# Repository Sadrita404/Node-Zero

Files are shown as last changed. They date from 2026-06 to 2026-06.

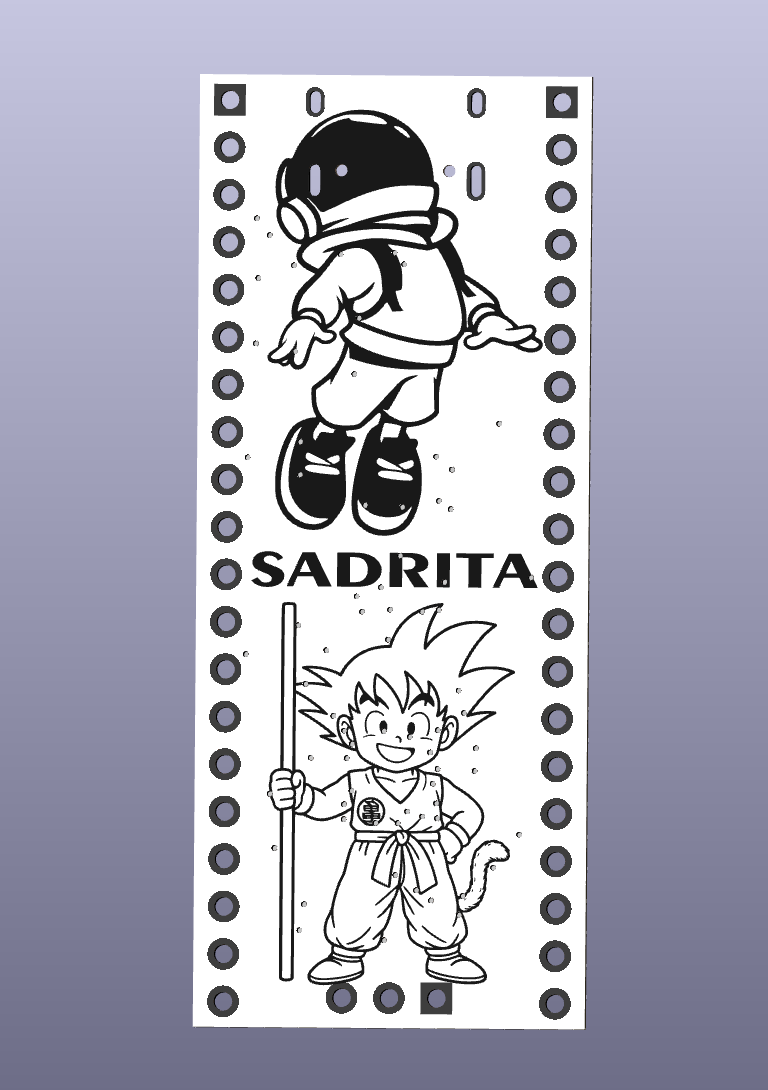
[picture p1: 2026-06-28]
Images/22.png

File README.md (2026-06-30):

<div align="center">
  <table border="0" cellpadding="0" cellspacing="0">
    <tr>
      <td align="center" style="background: #ffffff; border: 1px solid #d0d7de; border-radius: 12px; padding: 16px; box-shadow: 0 4px 12px rgba(0,0,0,0.05);">
        Rough Layout For The PCB
        <div style="margin-top: 12px; font-family: -apple-system, BlinkMacSystemFont, 'Segoe UI', Helvetica, Arial, sans-serif; font-size: 13px; color: #57606a; font-weight: 500;">
      </td>
    </tr>
  </table>
</div>

| Title | Node Zero |
| :-- | :---|
|Author |Sadrita Neogi|

## What's this?

Node Zero is an  rp2040 based micro-controller unit that consist of the rp2040 micro processor, the 16Mbit SPI NOR Flash, a crystal oscillator that synchronizes communication in the board between the USB abd rp2040, a voltage regulator, reset and boot switch.

## Why I built it ?

This is the starter project of stasis and I have not make any dev board ever before, so this is my the first time I am making an dev board so I am very excited to build this. That's why I am making the PCB whole custom thing. I have also get help from the detailed guide that is provided on the stasis website.

<div align="center">

| | PCB Designing | |
| :---: | :---: | :---: |
| Design 1 | Design 2 | Design 3 |
| Design 4 | Design 5 | Design 6 |
| Design 7 | Design 8 | Design 9 |

Screenshot 2026-06-30 at 8 58 29 PM

<div align="center">
  <h2> Final Look </h2>
  <table border="0" cellpadding="10" cellspacing="0" style="border-collapse: collapse;">
    <tr>
      <!-- FRONT SIDE CARD -->
      <td align="center" valign="top" width="50%" style="background: #ffffff; border: 1px solid #d0d7de; border-radius: 12px; padding: 16px; box-shadow: 0 4px 12px rgba(0,0,0,0.05);">
        Front Side View
        <div style="margin-top: 12px; font-family: -apple-system, BlinkMacSystemFont, 'Segoe UI', Helvetica, Arial, sans-serif; font-size: 13px; color: #57606a; font-weight: 600; text-transform: uppercase; letter-spacing: 0.5px;">
          ▲ Front Side View
        </div>
      </td>
      <!-- SPACER FOR GITHUB MOBILE DEGRADATION -->
      <td width="2%">&nbsp;</td>
      <!-- BACK SIDE CARD -->
      <td align="center" valign="top" width="50%" style="background: #ffffff; border: 1px solid #d0d7de; border-radius: 12px; padding: 16px; box-shadow: 0 4px 12px rgba(0,0,0,0.05);">
        Back Side View
        <div style="margin-top: 12px; font-family: -apple-system, BlinkMacSystemFont, 'Segoe UI', Helvetica, Arial, sans-serif; font-size: 13px; color: #57606a; font-weight: 600; text-transform: uppercase; letter-spacing: 0.5px;">
          ▲ Back Side View
        </div>
      </td>
    </tr>
  </table>
</div>
</div>

<div align="center">
  <h2> Bill of Materials </h2>
</div>

| Name | Purpose | Qty | Total (USD) | Link | Distributor |
| :--- | :--- | :---: | :---: | :---: | :--- |
| C9,C12 | 1uF 10V X5R ±10% 0402 MLCC | 20 | 0.1220 | [Link](https://lcsc.com/product-detail/C14445.html) | JLCPCB |
| C10,C11,C5,C8,C3,C2,C7,C6,C4,C17,C1,C20,C18 | 0.1uF (100nF) 16V X7R ±10% 0402 MLCC | 75 | 0.5775 | [Link](https://lcsc.com/product-detail/C1525.html) | JLCPCB |
| C13,C14 | 10uF 25V X5R ±10% 0805 MLCC | 20 | 4.3840 | [Link](https://lcsc.com/product-detail/C15850.html) | JLCPCB |
| C16,C15 | 33pF 50V C0G ±5% 0402 MLCC | 20 | 0.1160 | [Link](https://lcsc.com/product-detail/C1562.html) | JLCPCB |
| C19 | 10nF 50V X7R ±10% 0402 MLCC | 20 | 0.1740 | [Link](https://lcsc.com/product-detail/C15195.html) | JLCPCB |
| C21 | 2.2uF 6.3V X5R ±20% 0402 MLCC | 20 | 0.1660 | [Link](https://lcsc.com/product-detail/C12530.html) | JLCPCB |
| D3,D1,D2 | Red Water Clear 0603 LED Indication | 25 | 0.1800 | [Link](https://lcsc.com/product-detail/C2286.html) | JLCPCB |
| J1 | USB Type-C Receptacle 16P Female SMD R/A | 5 | 0.9170 | [Link](https://lcsc.com/product-detail/C165948.html) | JLCPCB |
| R2,R1 | 5.1kΩ 50V 62.5mW Thick Film Resistor ±1% 0402 | 20 | 0.0200 | [Link](https://lcsc.com/product-detail/C25905.html) | JLCPCB |
| R4,R3 | 30Ω 50V 62.5mW Thick Film Resistor ±5% 0402 | 20 | 0.0240 | [Link](https://lcsc.com/product-detail/C137883.html) | JLCPCB |
| R5,R7 | 1kΩ 50V 62.5mW Thick Film Resistor ±1% 0402 | 20 | 0.0820 | [Link](https://lcsc.com/product-detail/C11702.html) | JLCPCB |
| R6 | 10kΩ 50V 62.5mW Thick Film Resistor ±1% 0402 | 20 | 0.0640 | [Link](https://lcsc.com/product-detail/C25744.html) | JLCPCB |
| R10,R9,R8 | 470Ω 50V 62.5mW Thick Film Resistor ±1% 0402 | 25 | 0.0300 | [Link](https://lcsc.com/product-detail/C25117.html) | JLCPCB |
| SW1 | Tactile Switches 12V 50mA Black Button SMD SPST | 9 | 0.4950 | [Link](https://lcsc.com/product-detail/C720477.html) | JLCPCB |
| U1 | RP2040 Microcontroller (MCU) 133MHz LQFN-56 | 5 | 4.9045 | [Link](https://lcsc.com/product-detail/C2040.html) | JLCPCB |
| U2 | MCP1700T-3302E/TT Fixed 3.3V 250mA Linear LDO | 5 | 2.1595 | [Link](https://lcsc.com/product-detail/C39051.html) | JLCPCB |
| U3 | W25Q16JVUXIQ 16Mbit 133MHz SPI NOR FLASH USON-8 | 5 | 7.8745 | [Link](https://lcsc.com/product-detail/C2843335.html) | JLCPCB |
| U4 | ICM-20608-G 6-Axis IMU Accel + Gyro LGA-16 | 2 | 26.3282 | [Link](https://lcsc.com/product-detail/C78569.html) | JLCPCB |
| Y1 | 12MHz 20pF Crystal Oscillator SMD3225-4P | 7 | 0.6972 | [Link](https://lcsc.com/product-detail/C9002.html) | JLCPCB |
| PCB Fabrication (Node_Zero)	| 2-layer PCB — the board itself| 	5	| $2.00 |	—	 | JLCPCB |
| PCBA SMT Assembly|	SMT assembly of all SMD components| 	2| 	$41.63	| —	| JLCPCB |
| Shipping PCB	| E- Post (Cheapest) | 	- |	$11.74	| — | 	JLCPCB |
| Total | | | $104.69 | | | |

The project budget is $100 and my BOM is a $4 over that right now. But since I already have another project approved (a PCB business card),and I  order them both together that will cut down on shipping costs and bring the total under $100.

Also, this is my first time building a dev board and I don't have any experience soldering SMD components. Since I don't own a hot plate,So I wouldn't be able to assemble it manually myself and finish the project. So, to stay within that $100 budget, I'm going with PCB assembly instead.

#### Please approve this project it's my first devboard ....

**Project Under Hack Club**

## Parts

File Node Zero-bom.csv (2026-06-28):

Name | Purpose | Quantity | Total Cost (USD) | Link | Distributor
PCBA SMT Assembly | SMT assembly of all SMD components | 2 | 41.63 |  | JLCPCB
C10,C11,C5,C8,C3,C2,C7,C6,C4,C17,C1,C20,C18 | 0.1uF (100nF) 16V X7R ±10% 0402 MLCC | 75 | 0.58 | https://lcsc.com/product-detail/C1525.html | JLCPCB
C13,C14 | 10uF 25V X5R ±10% 0805 MLCC | 20 | 4.38 | https://lcsc.com/product-detail/C15850.html | JLCPCB
C16,C15 | 33pF 50V C0G ±5% 0402 MLCC | 20 | 0.12 | https://lcsc.com/product-detail/C1562.html | JLCPCB
C19 | 10nF 50V X7R ±10% 0402 MLCC | 20 | 0.17 | https://lcsc.com/product-detail/C15195.html | JLCPCB
C21 | 2.2uF 6.3V X5R ±20% 0402 MLCC | 20 | 0.17 | https://lcsc.com/product-detail/C12530.html | JLCPCB
D3,D1,D2 | Red Water Clear 0603 LED Indication | 25 | 0.18 | https://lcsc.com/product-detail/C2286.html | JLCPCB
J1 | USB Type-C Receptacle 16P Female SMD R/A | 5 | 0.92 | https://lcsc.com/product-detail/C165948.html | JLCPCB
R2,R1 | 5.1kΩ 50V 62.5mW Thick Film Resistor ±1% 0402 | 20 | 0.02 | https://lcsc.com/product-detail/C25905.html | JLCPCB
R4,R3 | 30Ω 50V 62.5mW Thick Film Resistor ±5% 0402 | 20 | 0.02 | https://lcsc.com/product-detail/C137883.html | JLCPCB
C9,C12 | 1uF 10V X5R ±10% 0402 MLCC | 20 | 0.12 | https://lcsc.com/product-detail/C14445.html | JLCPCB
R6 | 10kΩ 50V 62.5mW Thick Film Resistor ±1% 0402 | 20 | 0.06 | https://lcsc.com/product-detail/C25744.html | JLCPCB
R10,R9,R8 | 470Ω 50V 62.5mW Thick Film Resistor ±1% 0402 | 25 | 0.03 | https://lcsc.com/product-detail/C25117.html | JLCPCB
SW1 | Tactile Switches 12V 50mA Black Button SMD SPST | 9 | 0.49 | https://lcsc.com/product-detail/C720477.html | JLCPCB
U1 | RP2040 Microcontroller (MCU) 133MHz LQFN-56 | 5 | 4.90 | https://lcsc.com/product-detail/C2040.html | JLCPCB
U2 | MCP1700T-3302E/TT Fixed 3.3V 250mA Linear LDO | 5 | 2.16 | https://lcsc.com/product-detail/C39051.html | JLCPCB
U3 | W25Q16JVUXIQ 16Mbit 133MHz SPI NOR FLASH USON-8 | 5 | 7.87 | https://lcsc.com/product-detail/C2843335.html | JLCPCB
U4 | ICM-20608-G 6-Axis IMU Accel + Gyro LGA-16 | 2 | 26.33 | https://lcsc.com/product-detail/C78569.html | JLCPCB
Y1 | 12MHz 20pF Crystal Oscillator SMD3225-4P | 7 | 0.70 | https://lcsc.com/product-detail/C9002.html | JLCPCB
PCB Fabrication (Node_Zero) | 2-layer PCB — the board itself | 5 | 2.00 |  | JLCPCB
R5,R7 | 1kΩ 50V 62.5mW Thick Film Resistor ±1% 0402 | 20 | 0.08 | https://lcsc.com/product-detail/C11702.html | JLCPCB

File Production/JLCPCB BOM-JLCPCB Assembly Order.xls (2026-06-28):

JLCPCB BOM Tool - BOM Matching
BOM name：JLCPCB BOM-JLCPCB Assembly Order.xlsx |  |  | Download Time：2026-06-28 22:19:41 |  |  |  | * Our matching results are updated in real-time, but stock and prices may change. If it's been over 24 hours, please re-match before placing your order.
PCB Assembled Qty：5 |  |  | Est. Total Price：53.8907
Your BOM |  |  |  |  | Matched Parts |  |  |  |  |  |  | Order Information
Top Designator | Bottom Designator | Comment | Footprint | JLCPCB Part # | Matches | Part # | Manufacturer | Footprint | Description | Category | Warning | JLCPCB Part # | Product link | Lib Type | Qty | Source | Total Price ($)
C9,C12 |  | 1uF | C_0402_1005Metric |  | Select by System | CL05A105KP5NNNC | Samsung Electro-Mechanics | 0402 | 10V 1uF X5R ±10% 0402 Multilayer Ceramic Capacitors MLCC - SMD/SMT ROHS | Multilayer Ceramic Capacitors MLCC - SMD/SMT |  | C14445 | https://jlcpcb.com/partdetail/15107-CL05A105KP5NNNC/C14445 | Extended | 20 | 20 JLCPCB | 0.122
C10,C11,C5,C8,C3,C2,C7,C6,C4,C17,C1,C20,C18 |  | 0.1uF | C_0402_1005Metric |  | Select by System | CL05B104KO5NNNC | Samsung Electro-Mechanics | 0402 | 100nF 16V X7R ±10% 0402 Multilayer Ceramic Capacitors MLCC - SMD/SMT ROHS | Multilayer Ceramic Capacitors MLCC - SMD/SMT |  | C1525 | https://jlcpcb.com/partdetail/1877-CL05B104KO5NNNC/C1525 | Basic | 75 | 75 JLCPCB | 0.5775
C13,C14 |  | 10uF | C_0201_0603Metric |  | Select by System | CL21A106KAYNNNE | Samsung Electro-Mechanics | 0805 | 10uF 25V X5R ±10% 0805 Multilayer Ceramic Capacitors MLCC - SMD/SMT ROHS | Multilayer Ceramic Capacitors MLCC - SMD/SMT |  | C15850 | https://jlcpcb.com/partdetail/16532-CL21A106KAYNNNE/C15850 | Basic | 20 | 20 JLCPCB | 4.384
C16,C15 |  | 33pF | C_0402_1005Metric |  | Select by System | 0402CG330J500NT | FH (Guangdong Fenghua Advanced Tech) | 0402 | 33pF 50V C0G ±5% 0402 Multilayer Ceramic Capacitors MLCC - SMD/SMT ROHS | Multilayer Ceramic Capacitors MLCC - SMD/SMT |  | C1562 | https://jlcpcb.com/partdetail/1914-0402CG330J500NT/C1562 | Basic | 20 | 20 JLCPCB | 0.116
C19 |  | 10nF | C_0402_1005Metric |  | Select by System | CL05B103KB5NNNC | Samsung Electro-Mechanics | 0402 | 10nF 50V X7R ±10% 0402 Multilayer Ceramic Capacitors MLCC - SMD/SMT ROHS | Multilayer Ceramic Capacitors MLCC - SMD/SMT |  | C15195 | https://jlcpcb.com/partdetail/15869-CL05B103KB5NNNC/C15195 | Basic | 20 | 20 JLCPCB | 0.174
C21 |  | 2.2uF | C_0402_1005Metric |  | Select by System | CL05A225MQ5NSNC | Samsung Electro-Mechanics | 0402 | 2.2uF 6.3V X5R ±20% 0402 Multilayer Ceramic Capacitors MLCC - SMD/SMT ROHS | Multilayer Ceramic Capacitors MLCC - SMD/SMT |  | C12530 | https://jlcpcb.com/partdetail/13164-CL05A225MQ5NSNC/C12530 | Basic | 20 | 20 JLCPCB | 0.166
D3,D1,D2 |  | LED | LED_0603_1608Metric |  | Select by System | KT-0603R | Hubei KENTO Elec | 0603 | -40℃~+85℃ 1.8V~2.4V 120° 20mA 300mcd 40mW 615nm~630nm 645nm Discrete Diode Red Water Clear 0603 LED Indication - Discrete ROHS | LED Indication - Discrete |  | C2286 | https://jlcpcb.com/partdetail/Hubei_KENTOElec-KT0603R/C2286 | Basic | 25 | 25 JLCPCB | 0.18
J1 |  | USB_C_Receptacle_USB2.0_14P | USB_C_Receptacle_HRO_TYPE-C-31-M-12 |  | Select by System | TYPE-C-31-M-12 | Korean Hroparts Elec | SMD | -30℃~+80℃ 1 10,000 cycles 16P 20V 5A 7.35mm Female Surface Mount, Right Angle Type-C SMD USB Connectors ROHS | USB Connectors |  | C165948 | https://jlcpcb.com/partdetail/Korean_HropartsElec-TYPE_C_31_M12/C165948 | Extended | 5 | 5 JLCPCB | 0.917
R2,R1 |  | 5.1K | R_0402_1005Metric |  | Select by System | 0402WGF5101TCE | UNI-ROYAL(Uniroyal Elec) | 0402 | -55℃~+155℃ 5.1kΩ 50V 62.5mW Thick Film Resistor ±1% ±100ppm/℃ 0402 Chip Resistor - Surface Mount ROHS | Chip Resistor - Surface Mount |  | C25905 | https://jlcpcb.com/partdetail/26648-0402WGF5101TCE/C25905 | Basic | 20 | 20 JLCPCB | 0.02
R4,R3 |  | 27 | R_0402_1005Metric |  | Select by Customer | RC0402JR-07300RL | YAGEO | 0402 | -55℃~+155℃ 300Ω 50V 62.5mW Thick Film Resistor ±100ppm/℃ ±5% 0402 Chip Resistor - Surface Mount ROHS | Chip Resistor - Surface Mount |  | C137885 | https://jlcpcb.com/partdetail/YAGEO-RC0402JR07300RL/C137885 | Extended | 20 | 20 JLCPCB | 0.024
R5,R7 |  | 1K | R_0402_1005Metric |  | Select by System | 0402WGF1001TCE | UNI-ROYAL(Uniroyal Elec) | 0402 | -55℃~+155℃ 1kΩ 50V 62.5mW Thick Film Resistor ±1% ±100ppm/℃ 0402 Chip Resistor - Surface Mount ROHS | Chip Resistor - Surface Mount |  | C11702 | https://jlcpcb.com/partdetail/12256-0402WGF1001TCE/C11702 | Basic | 20 | 20 JLCPCB | 0.082
R6 |  | 10K | R_0402_1005Metric |  | Select by System | 0402WGF1002TCE | UNI-ROYAL(Uniroyal Elec) | 0402 | -55℃~+155℃ 10kΩ 50V 62.5mW Thick Film Resistor ±1% ±100ppm/℃ 0402 Chip Resistor - Surface Mount ROHS | Chip Resistor - Surface Mount |  | C25744 | https://jlcpcb.com/partdetail/26487-0402WGF1002TCE/C25744 | Basic | 20 | 20 JLCPCB | 0.064
R10,R9,R8 |  | 680 | R_0402_1005Metric |  | Select by System | 0402WGF4700TCE | UNI-ROYAL(Uniroyal Elec) | 0402 | -55℃~+155℃ 470Ω 50V 62.5mW Thick Film Resistor ±1% ±100ppm/℃ 0402 Chip Resistor - Surface Mount ROHS | Chip Resistor - Surface Mount |  | C25117 | https://jlcpcb.com/partdetail/25860-0402WGF4700TCE/C25117 | Basic | 25 | 25 JLCPCB | 0.03
SW1 |  | SW_Push | SW_Push_SPST_NO_Alps_SKRK |  | Select by System | TS-1088-AR02016 | XUNPU | SMD,4x3mm | -30℃~+80℃ 1.6N 100,000 cycles 12V 2mm 3.9mm 3mm 50mA Black Round Button SMD(SMT) Tab SPST Surface Mount,Vertical Without Bracket SMD,4x3mm Tactile Switches ROHS | Tactile Switches |  | C720477 | https://jlcpcb.com/partdetail/XUNPU-TS_1088AR02016/C720477 | Basic | 9 | 9 JLCPCB | 0.495
U1 |  | RP2040 | QFN-56-1EP_7x7mm_P0.4mm_EP3.2x3.2mm |  | Select by System | RP2040 | Raspberry Pi | LQFN-56(7x7) | 12bit 133MHz 30 LQFN-56(7x7) Microcontrollers (MCU/MPU/SOC) ROHS | Microcontrollers (MCU/MPU/SOC) |  | C2040 | https://jlcpcb.com/partdetail/RaspberryPi-RP2040/C2040 | Extended | 5 | 5 JLCPCB | 4.9045
U2 |  | MCP1700x-330xxTT | SOT-23 |  | Select by System | MCP1700T-3302E/TT | Microchip Tech | SOT-23 | -40℃~+125℃@(Tj) 1 1.6uA 178mV@(250mA) 250mA 3.3V 44dB@(100Hz) 6V Fixed Over Temperature Protection、Short Circuit Protection Positive SOT-23 Voltage Regulators - Linear, Low Drop Out (LDO) Regulators ROHS | Voltage Regulators - Linear, Low Drop Out (LDO) Regulators |  | C39051 | https://jlcpcb.com/partdetail/MicrochipTech-MCP1700T_3302ETT/C39051 | Extended | 5 | 5 JLCPCB | 2.1595
U3 |  | W25Q128JVS | Winbond_USON-8-1EP_3x2mm_P0.5mm_EP0.2x1.6mm |  | Select by System | W25Q16JVUXIQ | Winbond Elec | USON-8-EP(2x3) | -40℃~+85℃ 100,000 cycles 10uA 133MHz 16Mbit 2.7V~3.6V 20 Years 3ms SPI USON-8-EP(2x3) NOR FLASH ROHS | NOR FLASH |  | C2843335 | https://jlcpcb.com/partdetail/WinbondElec-W25Q16JVUXIQ/C2843335 | Extended | 5 | 5 JLCPCB | 7.8745
U4 |  | -40℃~+85℃ 1.71V~3.45V 16bit 1KB 6uA IMU (accelerometer + gyroscope) SPI、I2C X,Y,Z X,Y,Z ±16g ±2000dps 运动事件检测 LGA-16(3x3) Accelerometers ROHS | LGA-16(3x3) |  | Select by Customer | ICM-20602 | TDK InvenSense | LGA-16(3x3) | -40℃~+85℃ 1.71V~3.45V 16bit 1KB 6uA IMU (accelerometer + gyroscope) SPI、I2C X,Y,Z X,Y,Z ±16g ±2000dps 运动事件检测 LGA-16(3x3) Accelerometers ROHS | Accelerometers |  | C97633 | https://jlcpcb.com/partdetail/TDKInvenSense-ICM20602/C97633 | Extended | 5 | 5 JLCPCB | 30.9035
Y1 |  | 12MHz | Crystal_SMD_3225-4Pin_3.2x2.5mm |  | Select by System | X322512MSB4SI | YXC Crystal Oscillators | SMD3225-4P | -40℃~+85℃ 12MHz 20pF Crystal Oscillator ±10ppm ±20ppm SMD3225-4P Crystals ROHS | Crystals |  | C9002 | https://jlcpcb.com/partdetail/YXC_CrystalOscillators-X322512MSB4SI/C9002 | Basic | 7 | 7 JLCPCB | 0.6972

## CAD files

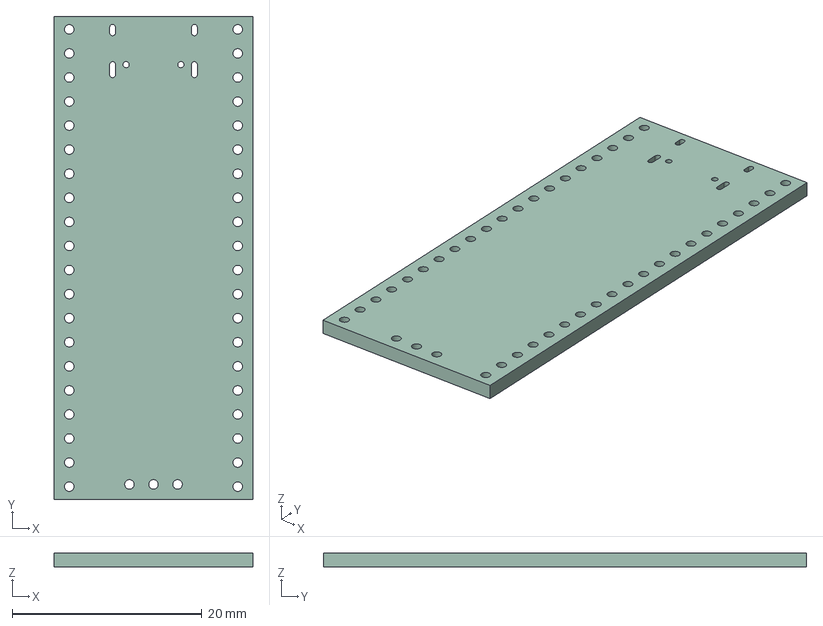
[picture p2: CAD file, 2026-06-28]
STEP/Node Zero .step
21.0 x 51.0 x 1.51 mm

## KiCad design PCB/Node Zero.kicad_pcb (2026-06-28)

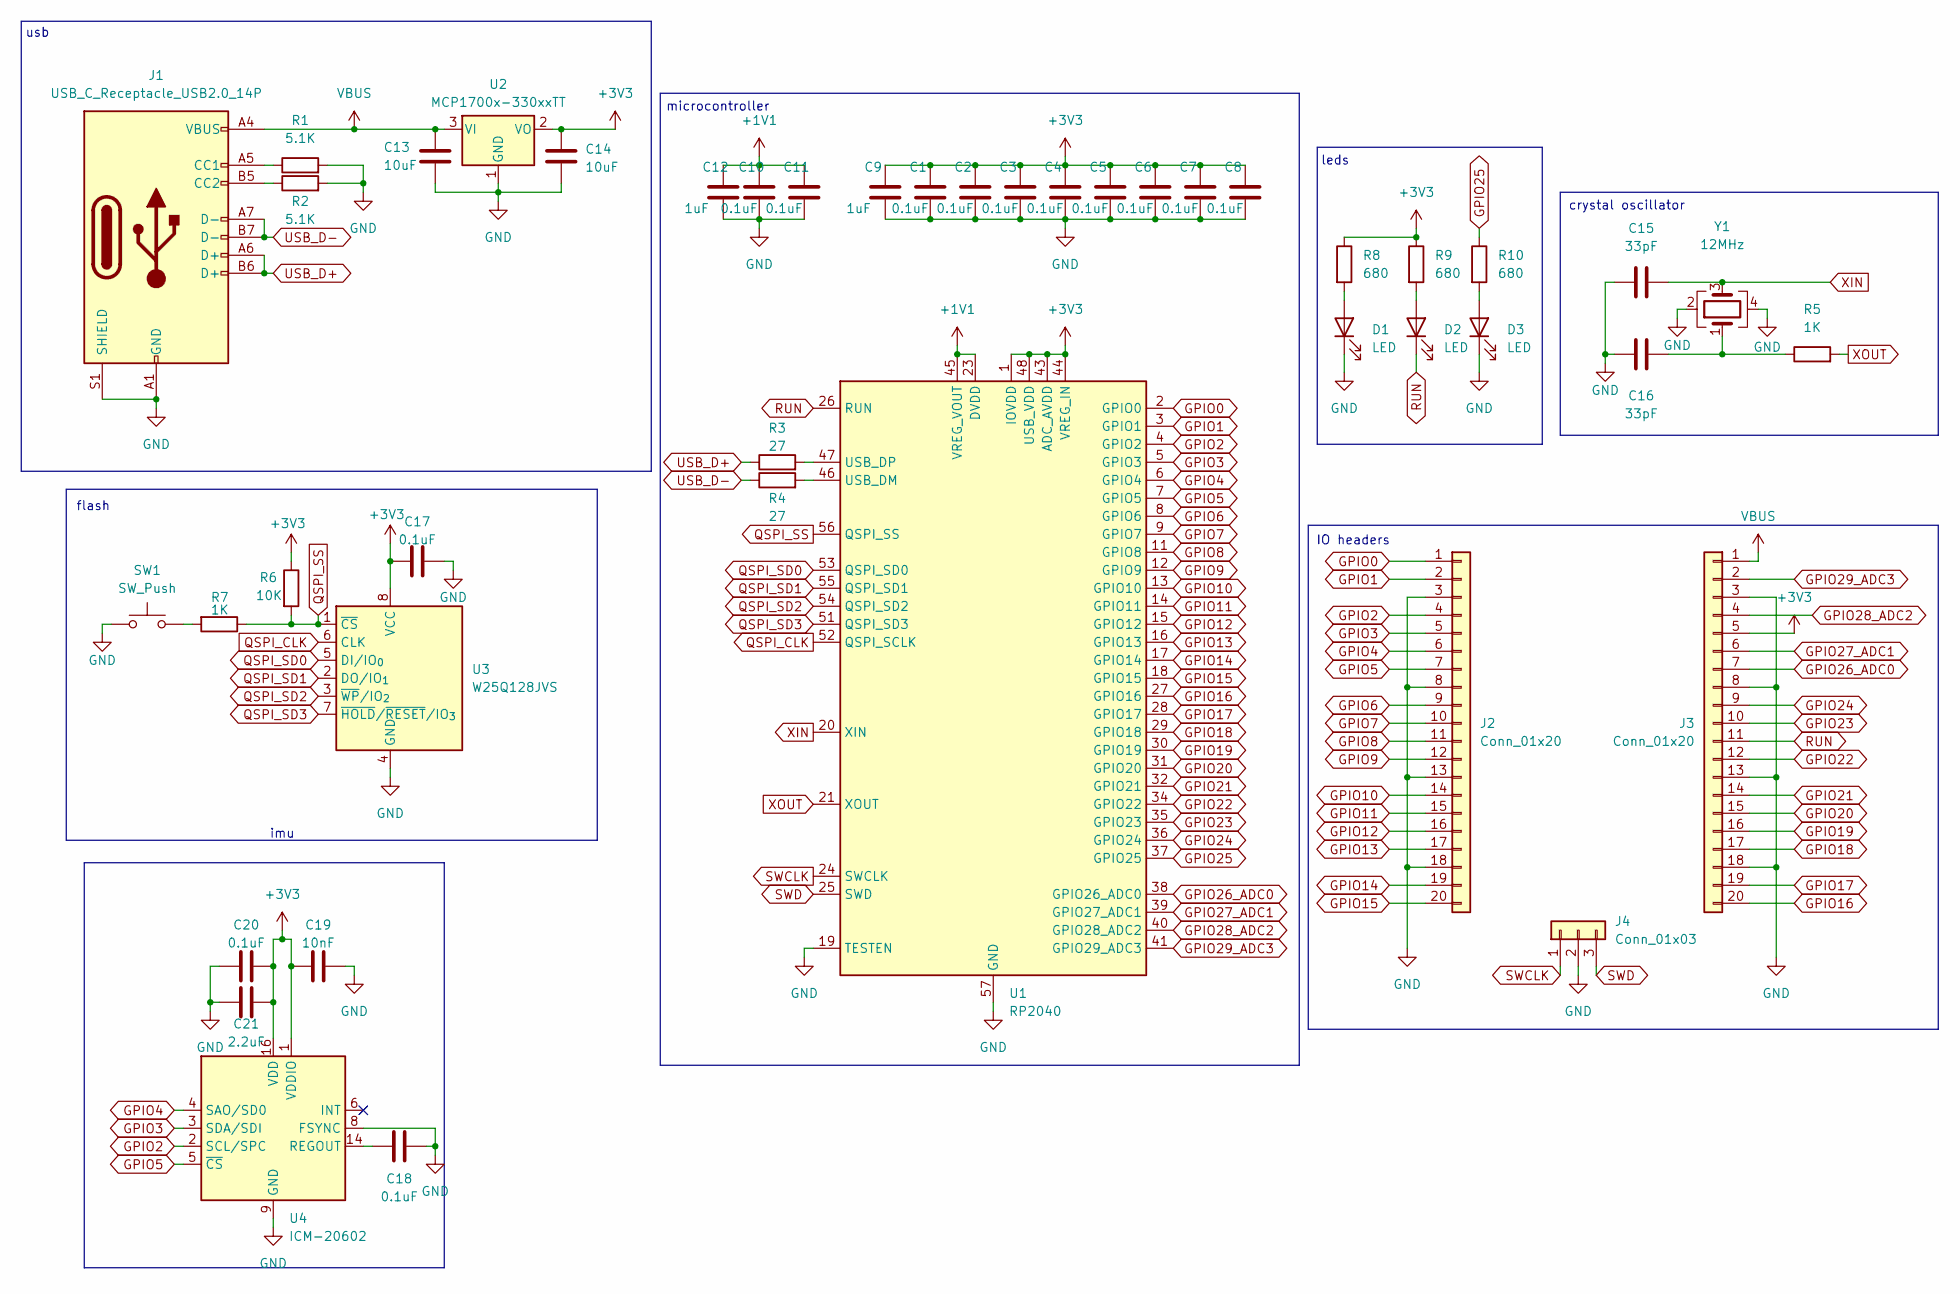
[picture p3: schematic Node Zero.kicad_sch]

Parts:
C1, C2, C3, C4, C5, C6, C7, C8, C10, C11, C17, C18, C20: 0.1uF; C_0402_1005Metric
C9, C12: 1uF; C_0402_1005Metric
C13, C14: 10uF; C_0603_1608Metric
C15, C16: 33pF; C_0402_1005Metric
C19: 10nF; C_0402_1005Metric
C21: 2.2uF; C_0402_1005Metric
D1, D2, D3: LED; LED_0603_1608Metric
J1: USB_C_Receptacle_USB2.0_14P; USB_C_Receptacle_HRO_TYPE-C-31-M-12
J2, J3: Conn_01x20; PinHeader_1x20_P2.54mm_Vertical
J4: Conn_01x03; PinHeader_1x03_P2.54mm_Vertical
R1, R2: 5.1K; R_0402_1005Metric
R3, R4: 27; R_0402_1005Metric
R5, R7: 1K; R_0402_1005Metric
R6: 10K; R_0402_1005Metric
R8, R9, R10: 680; R_0402_1005Metric
SW1: SW_Push; SW_Push_SPST_NO_Alps_SKRK
U1: RP2040; QFN-56-1EP_7x7mm_P0.4mm_EP3.2x3.2mm
U2: MCP1700x-330xxTT; SOT-23
U3: W25Q128JVS; Winbond_USON-8-1EP_3x2mm_P0.5mm_EP0.2x1.6mm
U4: ICM-20602; LGA-16_3x3mm_P0.5mm_LayoutBorder3x5y
Y1: 12MHz; Crystal_SMD_3225-4Pin_3.2x2.5mm

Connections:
+1V1: C10.1, C11.1, C12.1, U1.23 (DVDD), U1.45 (VREG_VOUT), U1.50 (DVDD)
+3V3: C1.1, C2.1, C3.1, C4.1, C5.1, C6.1, C7.1, C8.1, C9.1, C14.1, C17.1, C19.1, C20.2, C21.2, J3.5, R6.1, R8.1, R9.1, U1.1 (IOVDD), U1.10 (IOVDD), U1.22 (IOVDD), U1.33 (IOVDD), U1.42 (IOVDD), U1.43 (ADC_AVDD), U1.44 (VREG_IN), U1.48 (USB_VDD), U1.49 (IOVDD), U2.2 (VO), U3.8 (VCC), U4.1 (VDDIO), U4.16 (VDD)
GND: C1.2, C2.2, C3.2, C4.2, C5.2, C6.2, C7.2, C8.2, C9.2, C10.2, C11.2, C12.2, C13.2, C14.2, C15.1, C16.1, C17.2, C18.2, C19.2, C20.1, C21.1, D1.1 (K), D3.1 (K), J1.A1 (GND), J1.A12 (GND), J1.B1 (GND), J1.B12 (GND), J1.S1 (SHIELD), J2.3, J2.8, J2.13, J2.18, J3.3, J3.8, J3.13, J3.18, J4.2, R1.2, R2.2, SW1.1, U1.19 (TESTEN), U1.57 (GND), U2.1 (GND), U3.4 (GND), U4.8 (FSYNC), U4.9 (GND), U4.10 (GND), U4.11 (GND), U4.12 (GND), U4.13 (GND), U4.15 (GND), Y1.2, Y1.4
GPIO0: J2.1, U1.2 (GPIO0)
GPIO1: J2.2, U1.3 (GPIO1)
GPIO2: J2.4, U1.4 (GPIO2), U4.2 (SCL/SPC)
GPIO3: J2.5, U1.5 (GPIO3), U4.3 (SDA/SDI)
GPIO4: J2.6, U1.6 (GPIO4), U4.4 (SAO/SD0)
GPIO5: J2.7, U1.7 (GPIO5), U4.5 (~CS)
GPIO6: J2.9, U1.8 (GPIO6)
GPIO7: J2.10, U1.9 (GPIO7)
GPIO8: J2.11, U1.11 (GPIO8)
GPIO9: J2.12, U1.12 (GPIO9)
GPIO10: J2.14, U1.13 (GPIO10)
GPIO11: J2.15, U1.14 (GPIO11)
GPIO12: J2.16, U1.15 (GPIO12)
GPIO13: J2.17, U1.16 (GPIO13)
GPIO14: J2.19, U1.17 (GPIO14)
GPIO15: J2.20, U1.18 (GPIO15)
GPIO16: J3.20, U1.27 (GPIO16)
GPIO17: J3.19, U1.28 (GPIO17)
GPIO18: J3.17, U1.29 (GPIO18)
GPIO19: J3.16, U1.30 (GPIO19)
GPIO20: J3.15, U1.31 (GPIO20)
GPIO21: J3.14, U1.32 (GPIO21)
GPIO22: J3.12, U1.34 (GPIO22)
GPIO23: J3.10, U1.35 (GPIO23)
GPIO24: J3.9, U1.36 (GPIO24)
GPIO25: R10.1, U1.37 (GPIO25)
GPIO26_ADC0: J3.7, U1.38 (GPIO26_ADC0)
GPIO27_ADC1: J3.6, U1.39 (GPIO27_ADC1)
GPIO28_ADC2: J3.4, U1.40 (GPIO28_ADC2)
GPIO29_ADC3: J3.2, U1.41 (GPIO29_ADC3)
unnamed: C16.2, R5.1, Y1.1
unnamed: D1.2 (A), R8.2
unnamed: D2.2 (A), R9.2
unnamed: D3.2 (A), R10.2
unnamed: J1.A5 (CC1), R1.1
unnamed: J1.B5 (CC2), R2.1
unnamed: R7.2, SW1.2
unnamed: R4.2, U1.46 (USB_DM)
unnamed: R3.2, U1.47 (USB_DP)
unnamed: C18.1, U4.14 (REGOUT)
QSPI_CLK: U1.52 (QSPI_SCLK), U3.6 (CLK)
QSPI_SD0: U1.53 (QSPI_SD0), U3.5 (DI/IO_{0})
QSPI_SD1: U1.55 (QSPI_SD1), U3.2 (DO/IO_{1})
QSPI_SD2: U1.54 (QSPI_SD2), U3.3 (~WP/IO_{2})
QSPI_SD3: U1.51 (QSPI_SD3), U3.7 (~HOLD/~RESET/IO_{3})
QSPI_SS: R6.2, R7.1, U1.56 (QSPI_SS), U3.1 (~CS)
RUN: D2.1 (K), J3.11, U1.26 (RUN)
SWCLK: J4.1, U1.24 (SWCLK)
SWD: J4.3, U1.25 (SWD)
USB_D+: J1.A6 (D+), J1.B6 (D+), R3.1
USB_D-: J1.A7 (D-), J1.B7 (D-), R4.1
VBUS: C13.1, J1.A4 (VBUS), J1.A9 (VBUS), J1.B4 (VBUS), J1.B9 (VBUS), J3.1, U2.3 (VI)
XIN: C15.2, U1.20 (XIN), Y1.3
XOUT: R5.2, U1.21 (XOUT)

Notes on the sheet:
leds
microcontroller
crystal oscillator
usb
IO headers
flash
imu

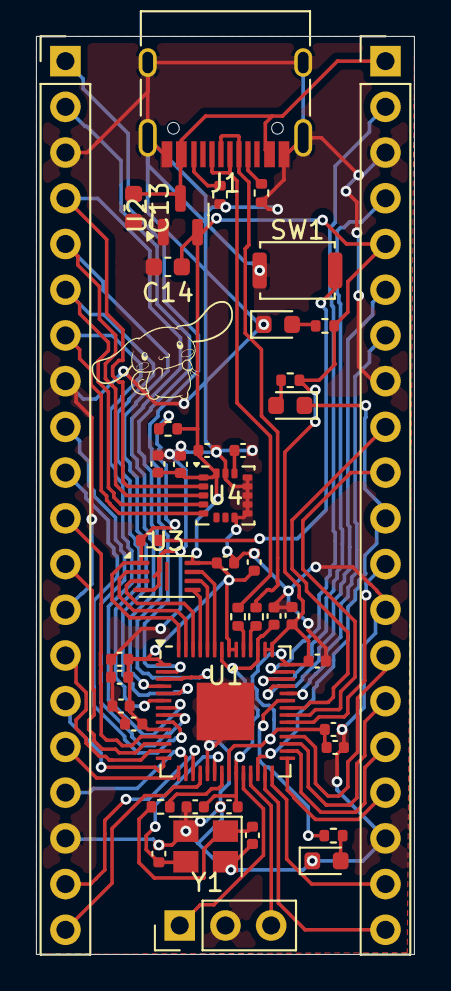
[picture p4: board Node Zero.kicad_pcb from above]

Board: 2 copper layers, 21.0 x 51.0 mm, 44 parts (0 on the bottom side), 57 nets.
